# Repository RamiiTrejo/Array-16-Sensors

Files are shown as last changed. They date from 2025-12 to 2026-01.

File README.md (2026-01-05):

# Array-16-Sensors
Regleta para Robot Seguidor de línea con 16 Sensores QRE1113, siendo multiplexados con dos CD4051, y siendo alimentados a 3,3v, sirviendo para Robots de Carreras, o Carreras Pro





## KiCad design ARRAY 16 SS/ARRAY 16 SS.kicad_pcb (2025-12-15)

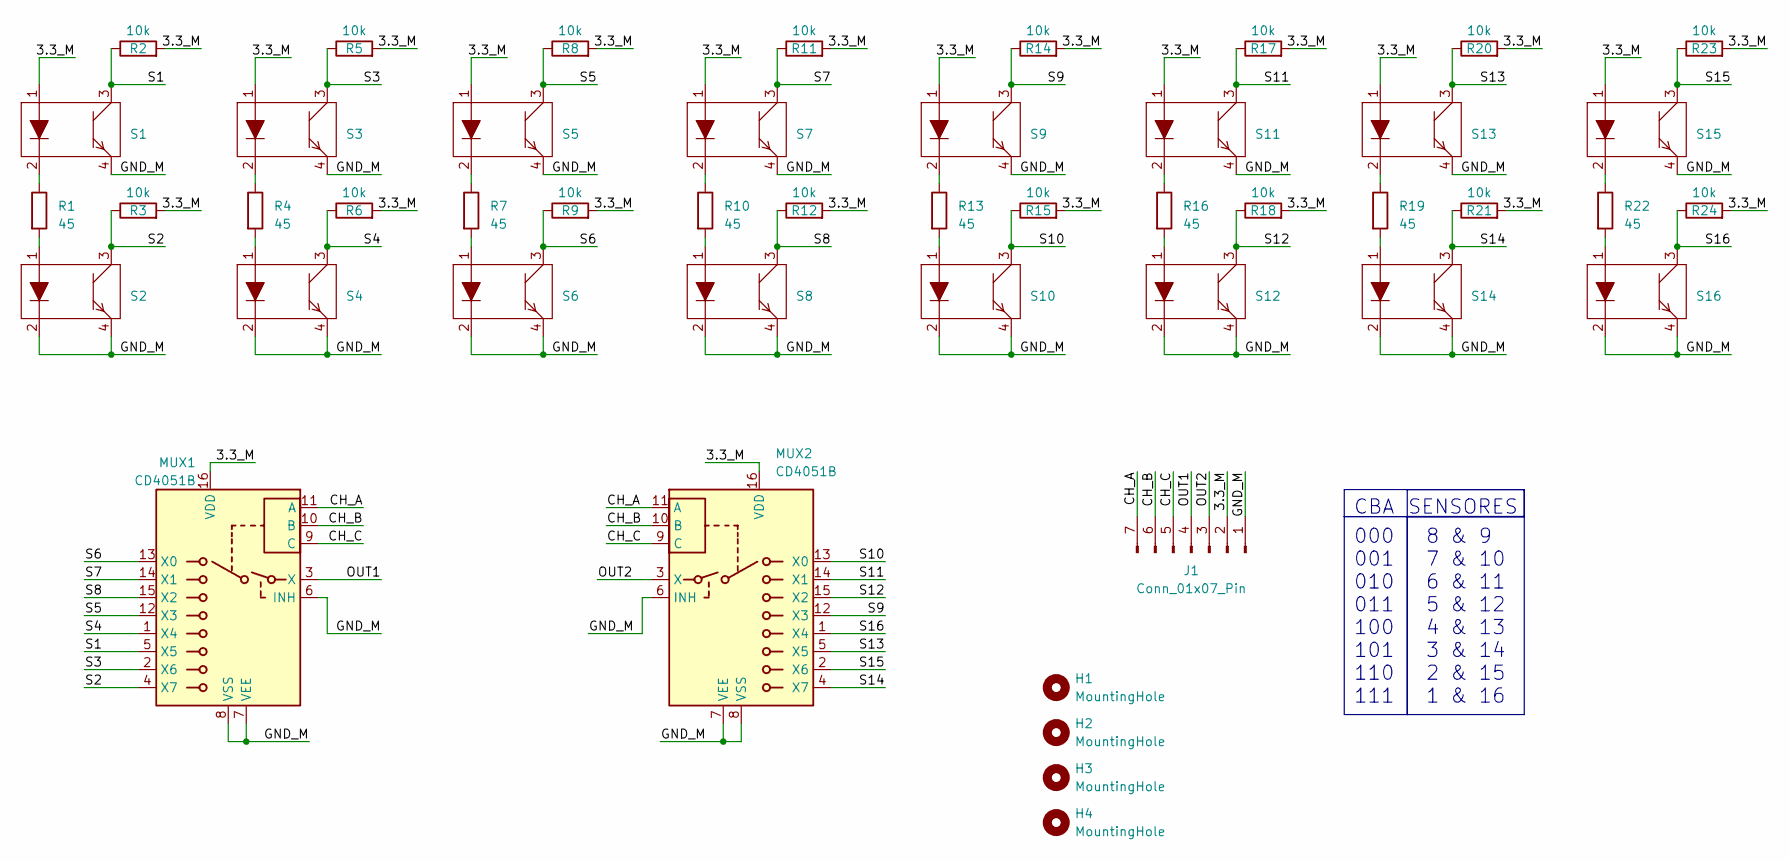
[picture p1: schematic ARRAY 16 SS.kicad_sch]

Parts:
H1, H2, H3, H4: MountingHole; MountingHole_3mm
J1: Conn_01x07_Pin; PinHeader_1x07_P2.54mm_Horizontal
MUX1, MUX2: CD4051B; SOIC-16W_5.3x10.2mm_P1.27mm; LCSC Part # C3007951
R1, R4, R7, R10, R13, R16, R19, R22: 45; R_0805_2012Metric_Pad1.20x1.40mm_HandSolder; LCSC Part # C3017827
R2, R3, R5, R6, R8, R9, R11, R12, R14, R15, R17, R18, R20, R21, R23, R24: 10k; R_0805_2012Metric_Pad1.20x1.40mm_HandSolder; LCSC Part # C17414
S1, S2, S3, S4, S5, S6, S7, S8, S9, S10, S11, S12, S13, S14, S15, S16: OnSemi_CASE100CY; LCSC Part # C81632

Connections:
/3.3_M: J1.2, MUX1.16 (VDD), MUX2.16 (VDD), R2.2, R3.2, R5.2, R6.2, R8.2, R9.2, R11.2, R12.2, R14.2, R15.2, R17.2, R18.2, R20.2, R21.2, R23.2, R24.2, S1.1, S3.1, S5.1, S7.1, S9.1, S11.1, S13.1, S15.1
/CH_A: J1.7, MUX1.11 (A), MUX2.11 (A)
/CH_B: J1.6, MUX1.10 (B), MUX2.10 (B)
/CH_C: J1.5, MUX1.9 (C), MUX2.9 (C)
/GND_M: J1.1, MUX1.6 (INH), MUX1.7 (VEE), MUX1.8 (VSS), MUX2.6 (INH), MUX2.7 (VEE), MUX2.8 (VSS), S1.4, S2.2, S2.4, S3.4, S4.2, S4.4, S5.4, S6.2, S6.4, S7.4, S8.2, S8.4, S9.4, S10.2, S10.4, S11.4, S12.2, S12.4, S13.4, S14.2, S14.4, S15.4, S16.2, S16.4
/OUT1: J1.4, MUX1.3 (X)
/OUT2: J1.3, MUX2.3 (X)
/S1: MUX1.5 (X5), R2.1, S1.3
/S2: MUX1.4 (X7), R3.1, S2.3
/S3: MUX1.2 (X6), R5.1, S3.3
/S4: MUX1.1 (X4), R6.1, S4.3
/S5: MUX1.12 (X3), R8.1, S5.3
/S6: MUX1.13 (X0), R9.1, S6.3
/S7: MUX1.14 (X1), R11.1, S7.3
/S8: MUX1.15 (X2), R12.1, S8.3
/S9: MUX2.12 (X3), R14.1, S9.3
/S10: MUX2.13 (X0), R15.1, S10.3
/S11: MUX2.14 (X1), R17.1, S11.3
/S12: MUX2.15 (X2), R18.1, S12.3
/S13: MUX2.5 (X5), R20.1, S13.3
/S14: MUX2.4 (X7), R21.1, S14.3
/S15: MUX2.2 (X6), R23.1, S15.3
/S16: MUX2.1 (X4), R24.1, S16.3
unnamed: R1.1, S1.2
unnamed: R1.2, S2.1
unnamed: R4.1, S3.2
unnamed: R4.2, S4.1
unnamed: R7.1, S5.2
unnamed: R7.2, S6.1
unnamed: R10.1, S7.2
unnamed: R10.2, S8.1
unnamed: R13.1, S9.2
unnamed: R13.2, S10.1
unnamed: R16.1, S11.2
unnamed: R16.2, S12.1
unnamed: R19.1, S13.2
unnamed: R19.2, S14.1
unnamed: R22.1, S15.2
unnamed: R22.2, S16.1

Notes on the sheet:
SENSORES
8 & 9 7 & 10 6 & 11 5 & 12 4 & 13 3 & 14 2 & 15 1 & 16
CBA
000 001 010 011 100 101 110 111

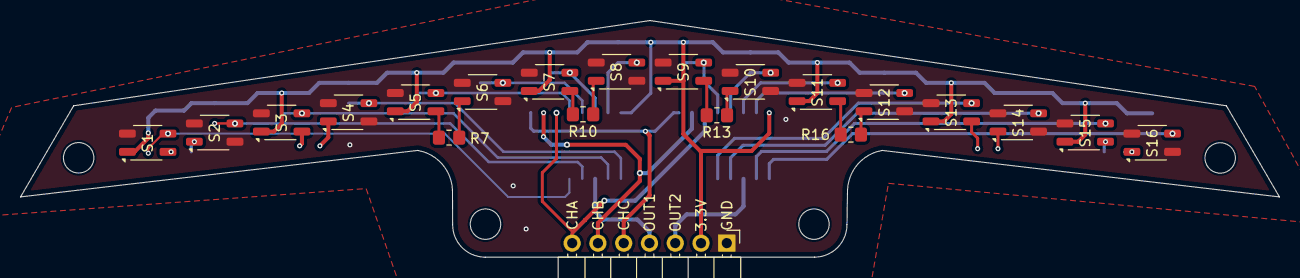
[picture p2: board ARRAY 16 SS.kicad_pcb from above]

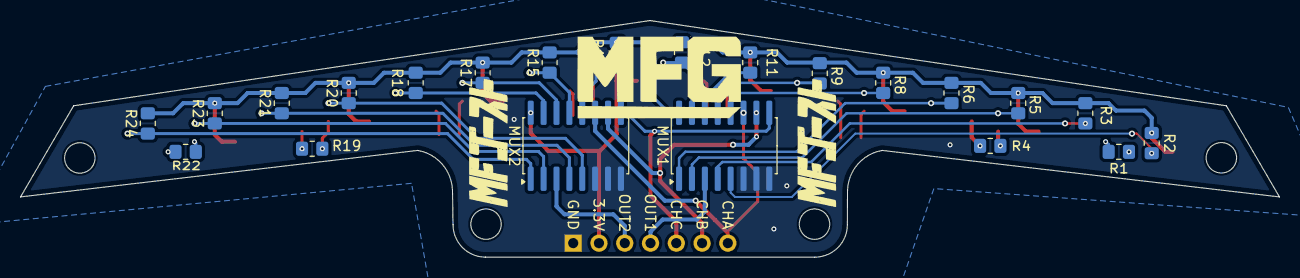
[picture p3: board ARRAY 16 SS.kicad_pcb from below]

Board: 2 copper layers, 124.1 x 23.3 mm, 47 parts (22 on the bottom side), 39 nets.
